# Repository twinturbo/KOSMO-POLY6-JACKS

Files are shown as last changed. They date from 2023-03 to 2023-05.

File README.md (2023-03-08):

# KOSMO-POLY6-JACKS

This repository contains KICAD Schematics, PCB and front panel to build a 6 voice jack board for the "Polykit" Inspired 6 Channel Synth in Kosmo Format [Look Mum No Computer LMNK] . The Jack board is intended as an output stage for the main DCO found here https://github.com/twinturbo/KOSMO-POLY6-PICO-DCO

## About KOSMO-POLY6
The [POLY6](https://github.com/twinturbo/KOSMO-POLY6) GIT contains the details of the porject as a whole, this is one module.

Other modules in the line up are

- KOSMO-POLY6-PICO-DCO - Complete [ DCO ](https://github.com/twinturbo/KOSMO-POLY6-PICO-DCO)
- KOSMO-POLY6-DRUID-DCO -(TBD).
- KOSMO-POLY6-JACKS - Complete. [ JACKS ](https://github.com/twinturbo/KOSMO-POLY6-JACKS)
- KOSMO-POLY6-MIX - In design.
- KOSMO-POLY6-ADSR - In Production with JLCPCB.
- KOSMO-POLY6-VCA - In design.
- KOSMO-POLY6-CONTROLS - (TBD).
- KOSMO-POLY6 Filter - (TBD).
- KOSMO-POLY6-PG Programmer - (TBD)
- KOSMO-POLY6-MetricST-Front-Panel - (TBD)

# KOSMO-POLY6-JACKS Details

The JACKS module has no real use in the finished POLY6 design and can be left out, however it can be useful in testing. It could be employed where you need to jump from one case or shelf to another, where having two of these cross patched with standdard 1/4 Leads could be of use ( although power would still need fed to the rest of the modules. 

## Key features

- 6 Jacks for Pulse Out ( normaled to the output header when not jacked )
- 6 Jacks for Ramp Out ( normaled to the output header when not jacked )
- 6 Jacks for Gate ( normaled to the output header when not jacked )
- +5v, +3.3v , +12V , -12V power pass through ( board itself is passive )

## Schematics and PCB
Schematics and PCB and front panle are in KICAD format.

- Front Panel PCB [Front](https://github.com/twinturbo/KOSMO-POLY6-JACKS/tree/master/HARDWARE/FRONT-PANEL)
- Jack PCB [Jack](https://github.com/twinturbo/KOSMO-POLY6-JACKS/tree/master/HARDWARE/JACK-BOARD)

Gerber files for the PCB and Front Panel can be found here [PLOT](https://github.com/twinturbo/KOSMO-POLY6-JACKS/tree/master/HARDWARE/PCB-PRINTS).

## Pictures
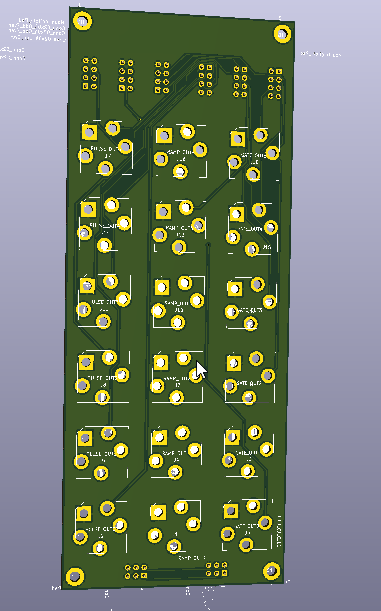
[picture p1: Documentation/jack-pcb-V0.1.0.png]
Kosmo DCO Jack PCB

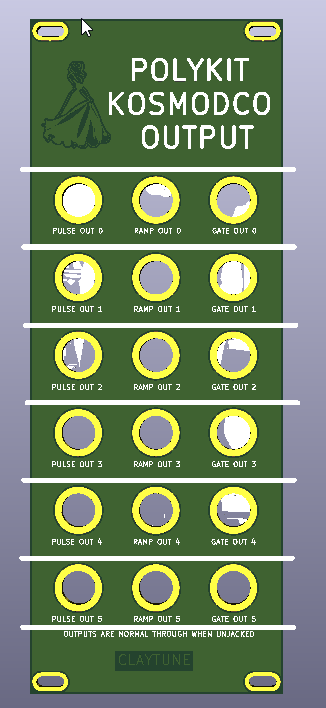
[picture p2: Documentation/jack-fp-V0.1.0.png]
Kosmo DCO Jack Front Panle


# References
- The Original DCO Project [ Original ](https://github.com/polykit/pico-dco)
- The LMNC project thread [ Thread ](https://lookmumnocomputer.discourse.group/t/kosmoing-the-polykit-dco/5878)
- The Publishing Thread of my POLY6 Modules [ Publish thread ](https://lookmumnocomputer.discourse.group/t/kosmo-poly6-releases/5962)
- Kosmo/LMNC forum [ Frorum Home ](https://lookmumnocomputer.discourse.group/)
- LMNC Webpage [ LMNC website](https://www.lookmumnocomputer.com/)
- LMNC Youtube [ LMNC Youetube](https://www.youtube.com/c/LOOKMUMNOCOMPUTER/videos)

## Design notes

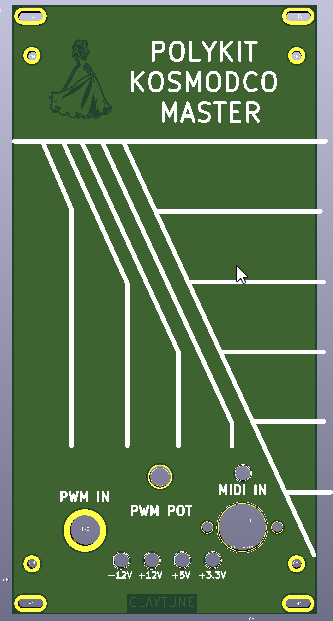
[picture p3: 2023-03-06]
Documentation/master-fp-V0.1.0.png

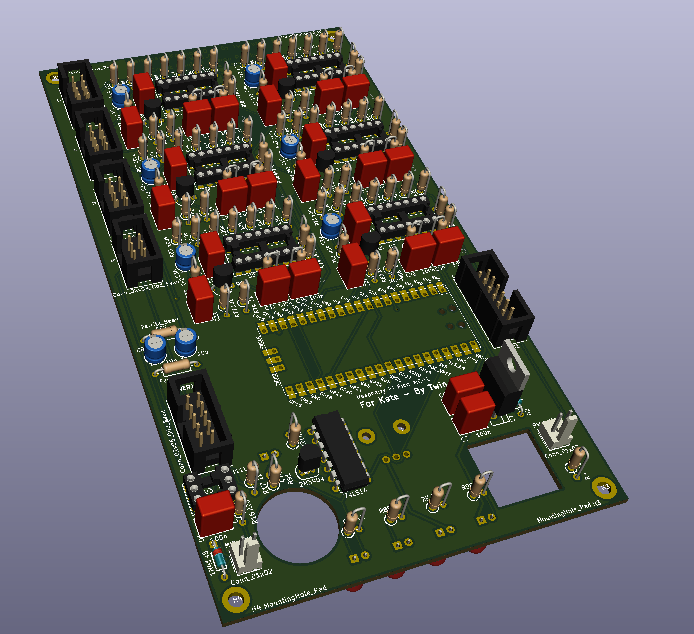
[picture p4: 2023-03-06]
Documentation/master-pcb-V0.1.0.png

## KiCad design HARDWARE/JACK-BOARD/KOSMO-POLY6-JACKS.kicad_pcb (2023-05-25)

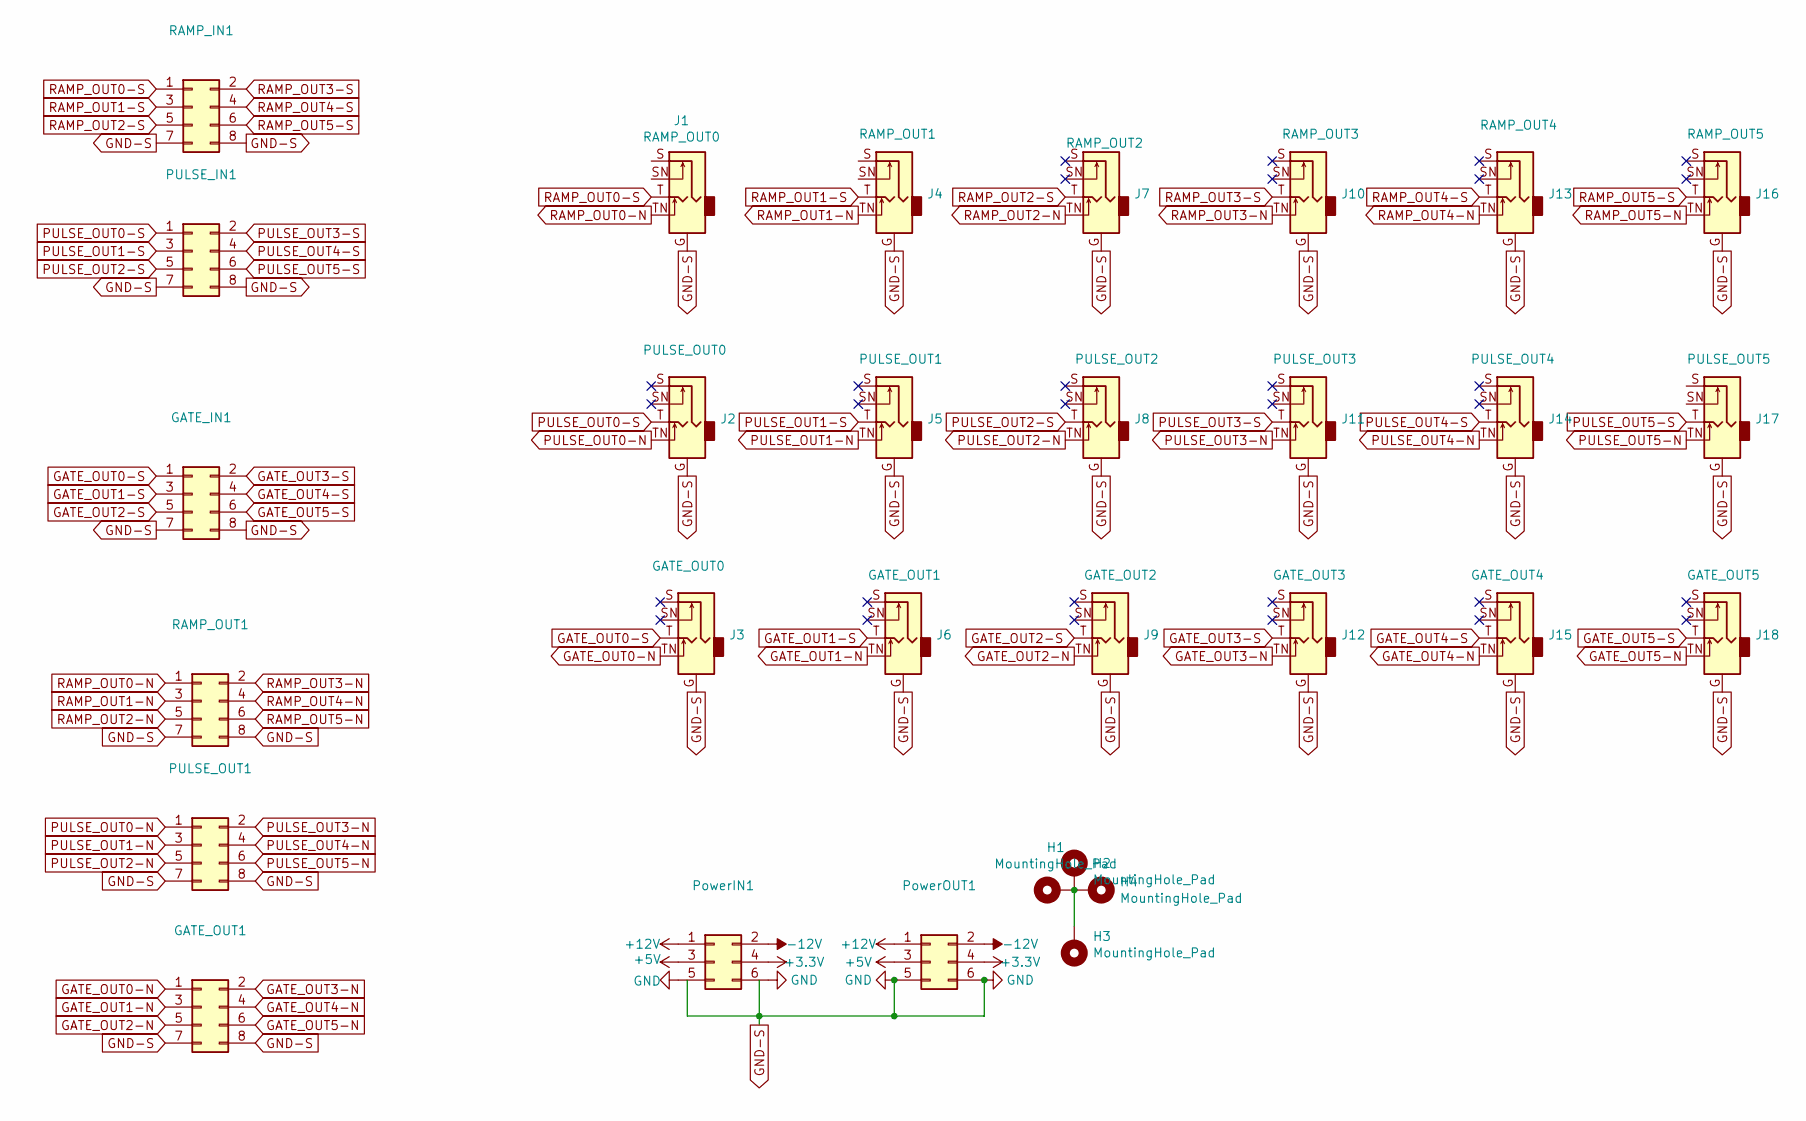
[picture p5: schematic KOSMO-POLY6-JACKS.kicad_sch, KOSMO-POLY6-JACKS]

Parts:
GATE_IN1: Conn_02x04_Odd_Even; IDC-Header_2x04_P2.54mm_Vertical
GATE_OUT1: Conn_02x04_Odd_Even; IDC-Header_2x04_P2.54mm_Vertical
H1, H2, H3, H4: MountingHole_Pad; MountingHole_3.2mm_M3_DIN965_Pad
J1: RAMP_OUT0; Jack_6.5mmLMNC
J2: PULSE_OUT0; Jack_6.5mmLMNC
J3: GATE_OUT0; Jack_6.5mmLMNC
J4: RAMP_OUT1; Jack_6.5mmLMNC
J5: PULSE_OUT1; Jack_6.5mmLMNC
J6: GATE_OUT1; Jack_6.5mmLMNC
J7: RAMP_OUT2; Jack_6.5mmLMNC
J8: PULSE_OUT2; Jack_6.5mmLMNC
J9: GATE_OUT2; Jack_6.5mmLMNC
J10: RAMP_OUT3; Jack_6.5mmLMNC
J11: PULSE_OUT3; Jack_6.5mmLMNC
J12: GATE_OUT3; Jack_6.5mmLMNC
J13: RAMP_OUT4; Jack_6.5mmLMNC
J14: PULSE_OUT4; Jack_6.5mmLMNC
J15: GATE_OUT4; Jack_6.5mmLMNC
J16: RAMP_OUT5; Jack_6.5mmLMNC
J17: PULSE_OUT5; Jack_6.5mmLMNC
J18: GATE_OUT5; Jack_6.5mmLMNC
PULSE_IN1: Conn_02x04_Odd_Even; IDC-Header_2x04_P2.54mm_Vertical
PULSE_OUT1: Conn_02x04_Odd_Even; IDC-Header_2x04_P2.54mm_Vertical
PowerIN1: Conn_02x03_Odd_Even; IDC-Header_2x03_P2.54mm_Vertical
PowerOUT1: Conn_02x03_Odd_Even; IDC-Header_2x03_P2.54mm_Vertical
RAMP_IN1: Conn_02x04_Odd_Even; IDC-Header_2x04_P2.54mm_Vertical
RAMP_OUT1: Conn_02x04_Odd_Even; IDC-Header_2x04_P2.54mm_Vertical

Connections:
+3V3: PowerIN1.4, PowerOUT1.4
+5V: PowerIN1.3, PowerOUT1.3
+12V: PowerIN1.1, PowerOUT1.1
-12V: PowerIN1.2, PowerOUT1.2
GATE_OUT0-N: GATE_OUT1.1, J3.TN
GATE_OUT0-S: GATE_IN1.1, J3.T
GATE_OUT1-N: GATE_OUT1.3, J6.TN
GATE_OUT1-S: GATE_IN1.3, J6.T
GATE_OUT2-N: GATE_OUT1.5, J9.TN
GATE_OUT2-S: GATE_IN1.5, J9.T
GATE_OUT3-N: GATE_OUT1.2, J12.TN
GATE_OUT3-S: GATE_IN1.2, J12.T
GATE_OUT4-N: GATE_OUT1.4, J15.TN
GATE_OUT4-S: GATE_IN1.4, J15.T
GATE_OUT5-N: GATE_OUT1.6, J18.TN
GATE_OUT5-S: GATE_IN1.6, J18.T
GND-S: GATE_IN1.7, GATE_IN1.8, GATE_OUT1.7, GATE_OUT1.8, J1.G, J2.G, J3.G, J4.G, J5.G, J6.G, J7.G, J8.G, J9.G, J10.G, J11.G, J12.G, J13.G, J14.G, J15.G, J16.G, J17.G, J18.G, PULSE_IN1.7, PULSE_IN1.8, PULSE_OUT1.7, PULSE_OUT1.8, PowerIN1.5, PowerIN1.6, PowerOUT1.5, PowerOUT1.6, RAMP_IN1.7, RAMP_IN1.8, RAMP_OUT1.7, RAMP_OUT1.8
unnamed: H1.1, H2.1, H3.1, H4.1
PULSE_OUT0-N: J2.TN, PULSE_OUT1.1
PULSE_OUT0-S: J2.T, PULSE_IN1.1
PULSE_OUT1-N: J5.TN, PULSE_OUT1.3
PULSE_OUT1-S: J5.T, PULSE_IN1.3
PULSE_OUT2-N: J8.TN, PULSE_OUT1.5
PULSE_OUT2-S: J8.T, PULSE_IN1.5
PULSE_OUT3-N: J11.TN, PULSE_OUT1.2
PULSE_OUT3-S: J11.T, PULSE_IN1.2
PULSE_OUT4-N: J14.TN, PULSE_OUT1.4
PULSE_OUT4-S: J14.T, PULSE_IN1.4
PULSE_OUT5-N: J17.TN, PULSE_OUT1.6
PULSE_OUT5-S: J17.T, PULSE_IN1.6
RAMP_OUT0-N: J1.TN, RAMP_OUT1.1
RAMP_OUT0-S: J1.T, RAMP_IN1.1
RAMP_OUT1-N: J4.TN, RAMP_OUT1.3
RAMP_OUT1-S: J4.T, RAMP_IN1.3
RAMP_OUT2-N: J7.TN, RAMP_OUT1.5
RAMP_OUT2-S: J7.T, RAMP_IN1.5
RAMP_OUT3-N: J10.TN, RAMP_OUT1.2
RAMP_OUT3-S: J10.T, RAMP_IN1.2
RAMP_OUT4-N: J13.TN, RAMP_OUT1.4
RAMP_OUT4-S: J13.T, RAMP_IN1.4
RAMP_OUT5-N: J16.TN, RAMP_OUT1.6
RAMP_OUT5-S: J16.T, RAMP_IN1.6

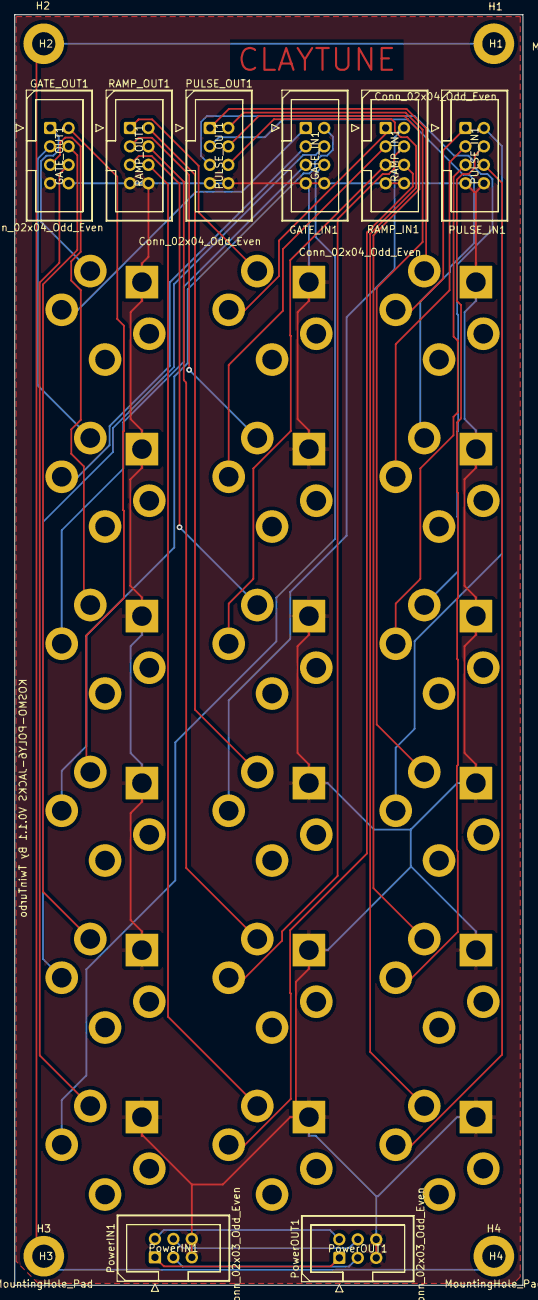
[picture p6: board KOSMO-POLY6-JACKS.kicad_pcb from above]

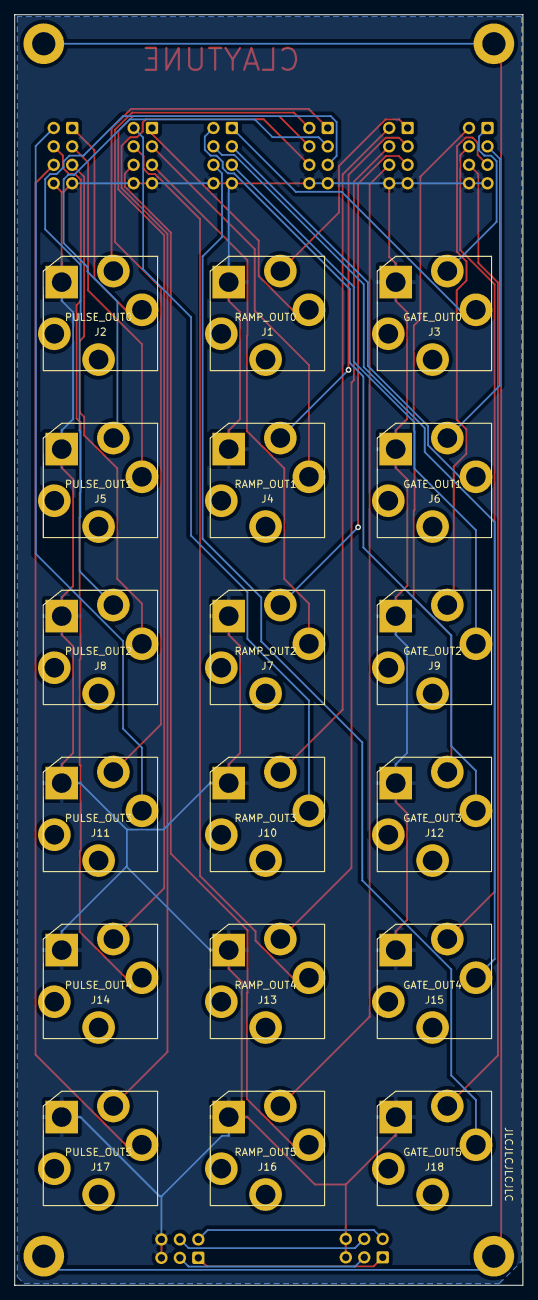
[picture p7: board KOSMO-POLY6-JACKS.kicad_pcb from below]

Board: 2 copper layers, 70.0 x 175.0 mm, 30 parts (18 on the bottom side), 42 nets.

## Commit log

2023-03-06 JACKS Seperated
    [JACK-Panel.kicad_pcb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]
2023-03-13 Kicad7 and Fixlayered
    [KOSMO-POLY6-JACKS-B_Cu.gbr, KOSMO-POLY6-JACKS-B_Mask.gbr, KOSMO-POLY6-JACKS-B_Paste.gbr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]
